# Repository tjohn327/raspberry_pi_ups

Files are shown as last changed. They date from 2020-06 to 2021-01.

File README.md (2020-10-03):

# UPS for Raspberry Pi

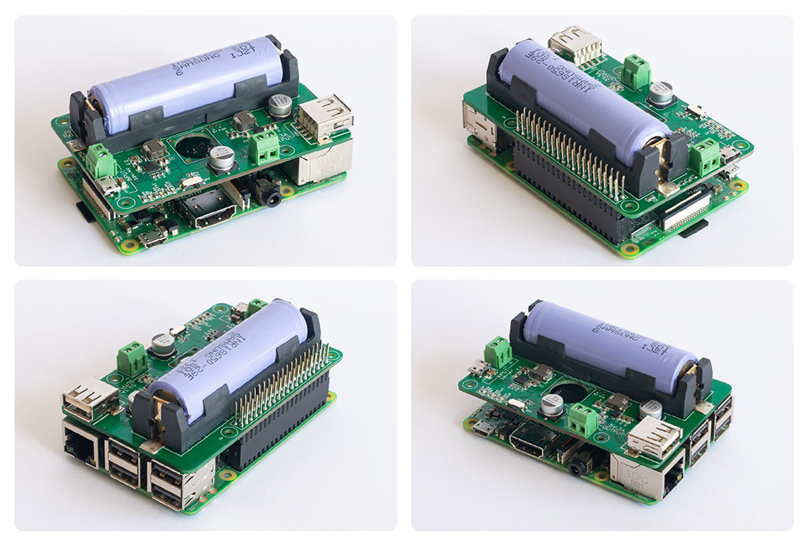
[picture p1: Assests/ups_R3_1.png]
UPS Image UPS powering a Raspberry Pi 3B+ model


## Description

An uninterruptible power supply for Raspberry Pi that can provide more than an hour of backup power and can shutdown the Pi safely.
This UPS can be used to power any 5V device with up to 3A continuous current. It is based on Texas Instruments [BQ25895](http://www.ti.com/product/BQ25895) power management IC and [TPS61236P](http://www.ti.com/product/TPS61236P) boost converter IC.

This UPS can power a Raspberry Pi through the GPIO header by using it as a hat. When used as a hat, the GPIO pins 2, 3 and 4 will be utilized for I2C and interrupt signals.

Note:  

* Do not connect two input sources together!

* The device does not have reverse polarity protection, be sure to observe the polarity marked in the battery holder while inserting the battery.

* UPS script was tested on a Raspberry Pi 3B+ running Raspbian Buster.

## Specifications

* Input:  4.5V - 14V DC, 2A - 5A

* Input Ports: Screw Terminal, micro USB

* Output: 5V, up to 3A

* Output Ports: Screw Terminal, USB A, 40 pin GPIO header for Raspberry Pi

* Battery: Not included (Samsung INR18650-29E recommended, other 18650 size li-Ion batteries can be used)

* Communication: I2C

## Status LEDs

* IN: Input connected or not

* STATUS: ON- Charging, OFF- Charging done, Blinking- Error

* OUT: Output on or off

## Setting up Power Pi for use with a Raspberry Pi

### 1. Connect Power Pi to Raspberry pi

* Make sure the switch of the Power Pi is turned off and no power input is connected to the Power Pi.

* Insert the battery into the battery holder of the Power Pi following the correct polarity.

* Connect Power Pi to Raspberry Pi by inserting it into the GPIO pins.

* Connect a USB power cable into the Raspberry Pi's USB input as usual to turn the Pi on. (This is to set up Power Pi. After the setup, power cable can be connected to Power Pi's input.)

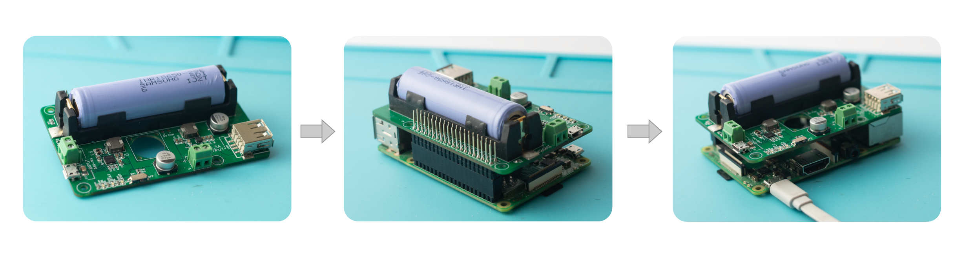
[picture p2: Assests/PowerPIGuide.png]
Setup Steps for setting up Power Pi


### 2. Set up Raspberry Pi to communicate with Power Pi

#### Enable I2C and install smbus

Update the system (optional):

```shell
sudo apt update && sudo apt upgrade -y
```

Enable I2C:

```shell
sudo raspi-config
```

Choose Interfacing Options, then I2C and then select enable to enable I2C in the Raspberry Pi.

Install smbus by running the following command:

```shell
sudo apt-get install -y python-smbus
```

For more information, checkout the [link](https://learn.adafruit.com/adafruits-raspberry-pi-lesson-4-gpio-setup/configuring-i2c)

### 3. Install the ups service

Clone the Power Pi repository:

```shell
cd ~
git clone https://github.com/tjohn327/raspberry_pi_ups.git
cd raspberry_pi_ups/src/
```

Edit the file powerpi.py between lines 16 and 24 if you are not using Samsung INR18650-29E battery. It is recommended to keep the VBAT_LOW at 3.2V for Li-Ion batteries.

*Power PI uses GPIO4 for interrupts from the Power Management IC. 1-Wire interface uses the same pin. If you are not using 1-Wire interface, disable it before proceeding. Power Pi can still function fully without the interrupt. So if you want to use 1-Wire interface it is advised to remove the resistor R12 from Power Pi, otherwise it will cause interference with 1-Wire interface.*

Run the install.sh script to install a service for the ups.

```shell
chmod +x install.sh
./install.sh
```

This creates a service named ups.service that will run on startup.
If there are no errors, you will see this as the output:

```shell
Checking Python
Python found
Initializing Power Pi
INFO:root:UPS initialized
Creating ups service
Enabling ups service to run on startup
ups service enabled
Power Pi configured successfully
```

Don't panic - since the Power is not connected to Power Pi this message will appear.

```shell
Broadcast message from user@raspberry (somewhere) (Sat Aug 15 18:40:10 2020):

Power Disconnected, system will shutdown in 72 minutes!
```

Now turn off the Raspberry Pi and remove the power cable form it. Connect the power cable to Power Pi and turn the switch to ON position. This will power up the Raspberry Pi through Power Pi.

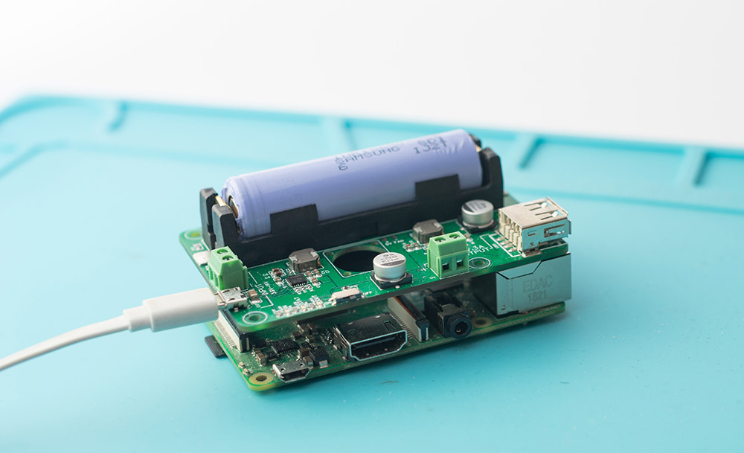
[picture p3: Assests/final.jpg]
PowerPi Power Pi powering the Raspberry Pi


When the Pi is powered back up, check the status of the ups service by running:

```shell
sudo systemctl status ups.service
```

If everything is running correctly, you will see a status similar to this:

```shell
● ups.service - UPS Service
   Loaded: loaded (/lib/systemd/system/ups.service; enabled; vendor preset: enabled)
   Active: active (running) since Tue 2020-06-09 06:44:15 UTC; 34s ago
 Main PID: 542 (python)
    Tasks: 2 (limit: 2200)
   Memory: 6.9M
   CGroup: /system.slice/ups.service
           └─542 /usr/bin/python /home/pi/code/raspberry_pi_ups/src/ups.py

Jun 09 06:44:15 raspberrypi systemd[1]: Started UPS Service.
Jun 09 06:44:17 raspberrypi python[542]: INFO:root:UPS initialized
```

Your Power Pi is now ready.

The ups service will now run on startup and send the status of the UPS to UDP Port 40001 every 2 seconds. You can see the status of the UPS by listening to that port.

To test if the UPS status is being read correctly, run the following command:

```shell
nc -lvu  40001
```

### 4. Setup Node-Red dashboard for visualization (optional)

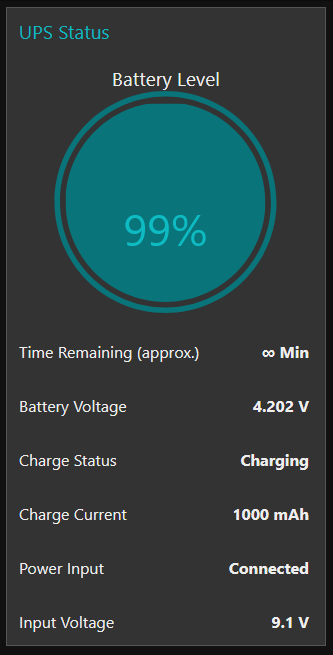
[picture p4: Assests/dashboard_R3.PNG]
Dashboard UPS Monitoring Dashboard


If you are new to Node-Red, please checkout their Essentials [video](https://www.youtube.com/watch?v=ksGeUD26Mw0&list=PLyNBB9VCLmo1hyO-4fIZ08gqFcXBkHy-6) series.

Follow the instructions given in the [link](https://nodered.org/docs/getting-started/raspberrypi) and install Node-Red on the Raspberry Pi.

It may take a while to install. After the installation is done, copy the ups_flow.json file to Node-Red's directory.

```shell
cp ups_flow.json ~/.node-red/lib/flows/ups_flow.json
```

Install the Dashboard extension for Node-Red.

```shell
cd ~/.node-red/
npm i node-red-dashboard
```

Enable Node-Red to run on startup and start the Node-Red service:

```shell
sudo systemctl enable nodered.service
sudo systemctl start nodered.service
```

Open the Node-Red link in a browser. The link is usually:

http://[IP of Raspberry Pi]:1880/

Import the ups flow into the Node-Red environment.

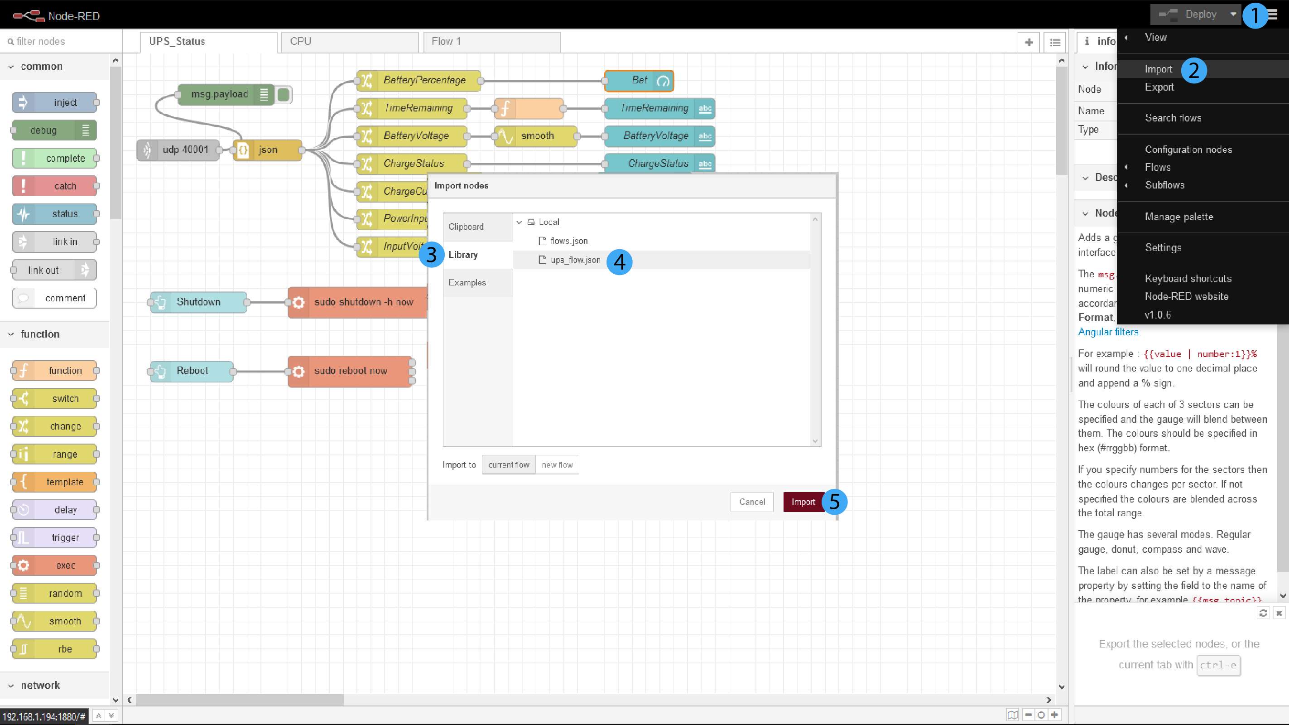
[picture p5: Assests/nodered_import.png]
Import Importing ups flow


Edit one of the UI nodes (e.g BAT) by double clicking on it. In its setup menu click on the edit button next to "Group' and select 'Home' in the Tab drop down. Click Update and then Done.

Deploy the flow by clicking the Deploy button and open the dashboard link of Node-Red to see the status of the UPS.

http://[IP of Raspberry Pi]:1880/ui

More [info](https://nodered.org/docs/user-guide/editor/workspace/import-export) about importing flows and setting up [dashboards](https://flows.nodered.org/node/node-red-dashboard).

## Using Power Pi with Raspberry Pi

When powering the Raspberry Pi through Power Pi, always connect the power cable to the input of the Power Pi. Use the switch of Power Pi to turn the devices ON and OFF.

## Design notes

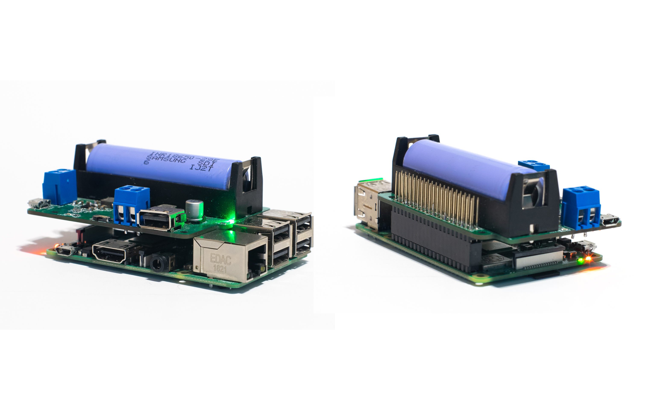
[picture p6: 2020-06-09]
Assests/UPSPi.png

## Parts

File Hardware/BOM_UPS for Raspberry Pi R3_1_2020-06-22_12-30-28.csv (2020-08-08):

ID | Name | Designator | Footprint | Quantity | Manufacturer Part | Manufacturer | Supplier | Supplier Part | LCSC Assembly | Remarks
1 | 10uF | C5,C6,C1,C7,C4,C8 | C0603 | 6 | GRM188R61E106KA73D | Murata Electronics | LCSC | C344022
2 | 10nF | C10 | C0603 | 1 | CL10B103KC8NNNC | SAMSUNG | LCSC | C84709 | Yes
3 | K3-1296S-E1 | SW1 | K3-1296S-E1 | 1 | K3-1296S-E1 | HRO | LCSC | C128955
4 | YJ-USB-AF-SMT-01 | USB1 | USB-A-SMD_FUS270-FSBW5K | 1 | YJ-USB-AF-SMT-01 | ValuePro | LCSC | C8328
5 | 10K | R3,R1,R2,R4,R5,R6,R10 | R0402 | 7 | RC0402FR-0710KL | YAGEO | LCSC | C60490
6 | 47nF | C2 | 402 | 1 | GRM155R71C473KA01D | MuRata | LCSC | C77012
7 | BQ25895RTWR | U1 | QFN-24_4X4X05P | 1 | BQ25895RTWR | TI | LCSC | C80200
8 | 2.2K | R7,R8,R9 | 603 | 3 | RC0603FR-072K2L | YAGEO | LCSC | C114662
9 | DB125-3.81-2P | U4,U6 | CONN-TH_2P-P3.81_L7.4-W7.6 | 2 | DB125-3.81-2P | DIBO | LCSC | C395878
10 | 1M | R11 | R0402 | 1 | RC0402FR-071ML | YAGEO | LCSC | C138033
11 | 19-217/G7C-AN1P2/3T | LED3,LED1 | LED0603-R-RD | 2 | 19-217/G7C-AN1P2/3T | EVERLIGHT | LCSC | C72042 | Yes
12 | 18650 SMD Bat Holder | BAT1 |  | 1 | Made in China |  |  |  |  | BAT1 cannot be in a reflow oven as it will deform. It should be solder after the SMT process.
13 | 33nF | C9 | C0603 | 1 | CL10B333KB8NNNC | SAMSUNG | LCSC | C21117 | Yes
14 | TPS61236PRWLR | U2 | VQFN-9_2.5X2.5 | 1 | TPS61236PRWLR | TI | LCSC | C130295
15 | 200K | R14 | R0603 | 1 | RC0603FR-07200KL | YAGEO | LCSC | C105574
16 | 1uH | L1,L2 | IND-SMD_L7.1-W6.5-P5.60 | 2 | SPM6530T-1R0M120 | TDK | LCSC | C87572
17 | 19-217/R6C-AL1M2VY/3T | LED2 | LED0603-R-RD | 1 | 19-217/R6C-AL1M2VY/3T | EVERLIGHT | LCSC | C72044 | Yes
18 | 10118194-0001LF | USB3 | MICRO-USB-SMD_10118194-0001LF | 1 | 10118194-0001LF | Amphenol ICC | LCSC | C132563
19 | 22uF | C17 | 1206 | 1 | CL31A226KAHNNNE | SAMSUNG | LCSC | C12891
20 | 620K | R13 | R0603 | 1 | CR0603-FX-6203ELF | BOURNS | LCSC | C203713
21 | 220uF | C13,C14 | CAP-SMD_BD8.0-L8.3-W8.3-FD | 2 | UWX1A221MCL1GB | Nichicon | LCSC | C125986
22 | SH-40P-8.5/5.0/10.5 | H2 |  | 1 | SH-40P-8.5/5.0/10.5 |  |  | https://www.alibaba.com/product-detail/Customize-2-20pin-8-5-5_60778133935.html?fullFirstScreen=true |  | H2 is to be inserted from the bottom layer as in the previous orders. Also please take care when soldering H2 as it should be soldered straight. In one of the previous orders one H2 was not soldered straight.
23 | 0 | R12 | R0603 | 1 | RC0603JR-070RL | YAGEO | LCSC | C95177
24 | 1uF | C3,C15 | C0603 | 2 | CL10A105KA8NNNC | SAMSUNG | LCSC | C5673 | Yes
25 | 22uF | C11,C12,C16 | C0603 | 3 | GRM188R61A226ME15D | MuRata | LCSC | C84419

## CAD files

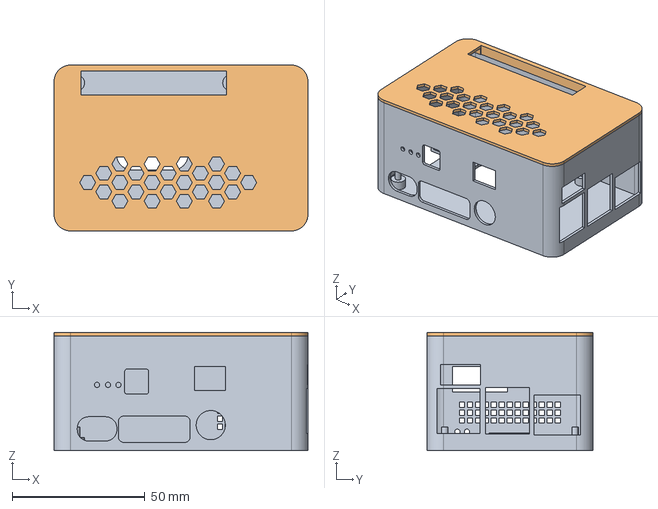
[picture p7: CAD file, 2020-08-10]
Enclosure/Enclosure_RPi4b.step
95.6 x 62.5 x 44.4 mm
Case
Top

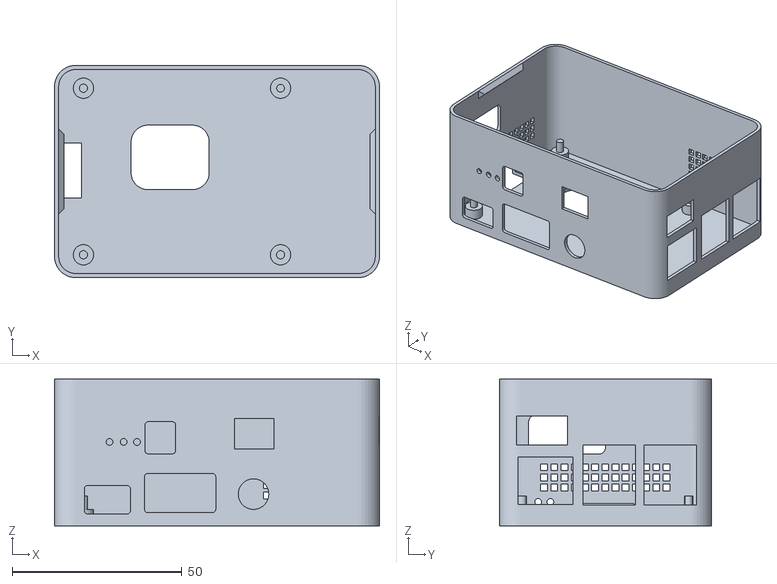
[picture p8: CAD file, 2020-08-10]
Enclosure/STL/RPi3b/Case.stl
95.6 x 62.5 x 43.2

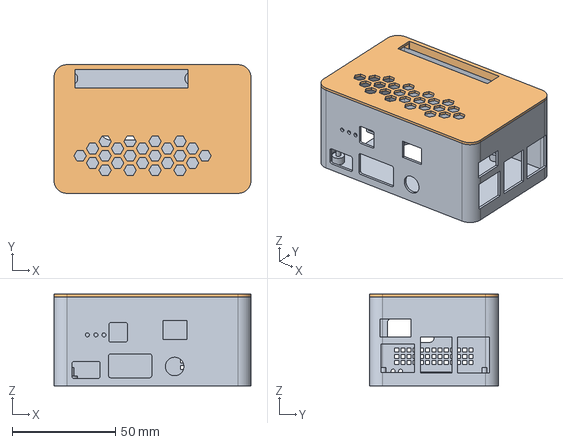
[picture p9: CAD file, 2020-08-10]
Enclosure/Enclosure_RPi3b.step
95.6 x 62.5 x 44.4 mm
Case
Top

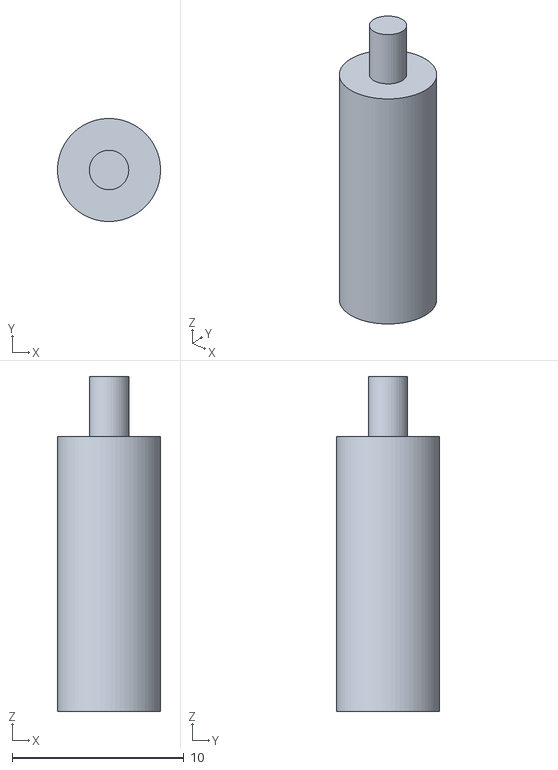
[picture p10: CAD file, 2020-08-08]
Enclosure/STL/RPi3b/Standoff.stl
6.00 x 6.00 x 19.5

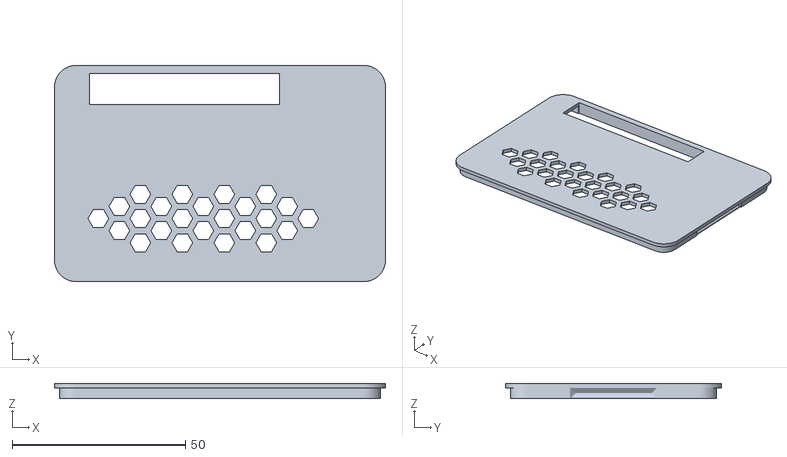
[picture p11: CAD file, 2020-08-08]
Enclosure/STL/RPi4b/Top.stl
95.6 x 62.5 x 4.23

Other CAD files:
Enclosure/STL/RPi4b/Case.stl
Enclosure/Standoff.step
Enclosure/STL/RPi3b/Top.stl

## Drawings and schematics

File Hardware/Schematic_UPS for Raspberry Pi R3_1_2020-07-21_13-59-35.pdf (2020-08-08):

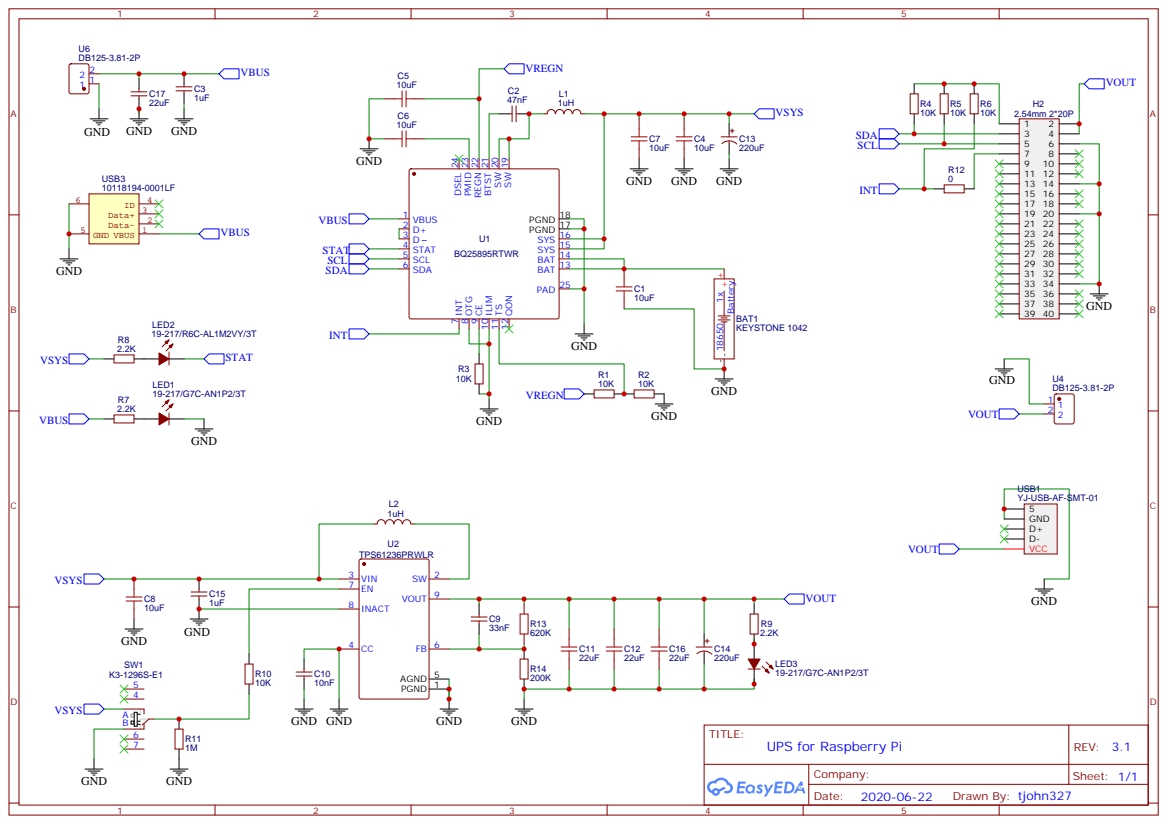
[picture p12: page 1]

BAT 13 BAT 14 SYS 15 SYS 16 PGND 17 PGND 18

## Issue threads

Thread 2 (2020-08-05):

integrate into other monitoring systems

DOliana, 2020-08-05:
I would like to monitor the Power Pi via OpenHab instead of node red. Could you provide some guidance on how monitoring of the Power Pi can be achieved so that it can be integrated into other systems like OpenHab?

tjohn327, 2020-08-05:
The status of Power Pi is being published as UDP message on the port 127.0.0.1:40001 by ups.service.

The messages are JSON formatted as follows:
{
    "BatteryPercentage": 87,
    "BatteryVoltage": 4.08,
    "ChargeCurrent": 0,
    "ChargeStatus": "Not Charging",
    "InputVoltage": 2.6,
    "PowerInputStatus": "Not Connected",
    "TimeRemaining": 76
}

DOliana, 2020-08-08:
thanks for the info - I will look into that. Have you thought about integrating MQTT?

poindexter12, 2020-08-18:
+1 for mqtt

DOliana, 2021-05-02:
If anybody is interested in testing/improving MQTT support - I added MQTT-Support in a [PR](https://github.com/tjohn327/raspberry_pi_ups/pull/10). Please review/improve it.

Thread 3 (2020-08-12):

Device and service failed to run

allibragi, 2020-08-12:
Hi,
I'm trying to setup the powerpi on a Banana PI PRO and, aside that the board is not supported, I'm facing 2 issues:

- Powering the Banana from the PowerPi doesn't work, I've checked the power requirements and the Banana is in the range 5 V @ 2 A

- The installation went ok, the Banana see the PowerPi and give the "Power Pi configured successfully" message, but the service fail to start. Checking the service status I've this error:

> ups.service - UPS Service
   Loaded: loaded (/lib/systemd/system/ups.service; enabled; vendor preset: enabled)
   Active: failed (Result: exit-code) since Wed 2020-08-12 19:43:42 UTC; 16s ago
  Process: 1660 ExecStart=/usr/bin/python /home/banano/raspberry_pi_ups/src/ups.py (code=exited, status=1/FAILURE)
 Main PID: 1660 (code=exited, status=1/FAILURE)
Aug 12 19:43:41 bananapipro systemd[1]: ups.service: Unit entered failed state.
Aug 12 19:43:41 bananapipro systemd[1]: ups.service: Failed with result 'exit-code'.
Aug 12 19:43:42 bananapipro systemd[1]: ups.service: Service hold-off time over, scheduling restart.
Aug 12 19:43:42 bananapipro systemd[1]: Stopped UPS Service.
Aug 12 19:43:42 bananapipro systemd[1]: ups.service: Start request repeated too quickly.
Aug 12 19:43:42 bananapipro systemd[1]: Failed to start UPS Service.
Aug 12 19:43:42 bananapipro systemd[1]: ups.service: Unit entered failed state.
Aug 12 19:43:42 bananapipro systemd[1]: ups.service: Failed with result 'exit-code'.

Anyhow the shipping was perfect and I've received the board without any problems.
Thank you!

tjohn327, 2020-08-12:
Hi,

Banana Pi is not supported by Power Pi for safe shutdown and status monitoring as it was never tested on it. But I guess this issue can be solved.  Nevertheless Power Pi can still power the Banana Pi through the 5V rail of the 40 pin connector if BananaPi supports being powered through the 5V rail. Other wise you'll have to use the USB A output of Power Pi.

For the ups.service file located at /lib/systemd/system/ups.service. See if the path to python and ups.py  after the ExecStart part is correct. Also. check if the username is correct.

tjohn327, 2020-08-12:
Hi,

Banana Pi is not supported by Power Pi for safe shutdown and status monitoring as it was never tested on it. But I guess this issue can be solved. Nevertheless Power Pi can still power the Banana Pi through the 5V rail of the 40 pin connector if BananaPi supports being powered through the 5V rail. Other wise you'll have to use the USB A output of Power Pi.

Check the ups.service file located at /lib/systemd/system/ups.service. See if the path to python and ups.py after the ExecStart part is correct. Also. check if the username is correct.

After correction, run the following:

```shell
sudo systemctl daemon-reload
sudo systemctl enable ups.service
sudo systemctl restart ups.service
```

allibragi, 2020-08-13:
Hi,

I've found the error in the process, it wasn't t able to find the RPi.GPIO library. I've installed it from the manufacturer repo (http://wiki.lemaker.org/BananaPro/Pi:GPIO_library).

For the powering I'm using a cable through the USB port. I think it could be possible to power it through the pins but i can't find any hint (plus I'm not experienced in this field). If anyone should come through this post and knows how to do it let me know.

tjohn327, 2020-08-14:
Hi,
Thank you very much for the feedback.
Have you connected the Power Pi to BananaPi as a HAT using the 40 Pin connector? If so, I don't think you need the cable to Power it, just turn the switch on and it should start powering the Banana Pi.

allibragi, 2020-08-14:
If i connect the Power Pi by the pins and flip the switch the Banana Pi simply don't turn on. The leds on the PowerPi shows that the battery is charging and that the output power is on.
If I power the PI normally the process see the HAT and shows the battery time left and that its not charging (obviously).

tjohn327, 2020-08-14:
That means Banana Pi does not support powering it through the 5V pins of the 40 pin connector.

allibragi, 2020-08-14:
I'll use it by the USB port, is not much a problem. I eventually switch to a PI 4.
Thanks for the help.

Closed 2020-08-14.

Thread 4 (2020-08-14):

Not charging

heronlen, 2020-08-14:
Hi I received the PowerPi, all configured, as per instructions and it runs the Pi when the power is disconnected, however it isn't charging the battery.

Running nc -lvu  40001

Listening on [0.0.0.0] (family 2, port 40001)
Connection from localhost 46547 received!
{
    "BatteryPercentage": 30,
    "BatteryVoltage": 3.504,
    "ChargeCurrent": 0,
    "ChargeStatus": "Not Charging",
    "InputVoltage": 2.6,
    "PowerInputStatus": "Not Connected",
    "TimeRemaining": 26
}

Thanks in advance.

kiddigital, 2020-08-14:
@heronlen , it also says that the PowerInputStatus is 'Not Connected'. So there is no power to charge from :)

Check the powersupply to the PowerPI to make sure the PowerPI gets power at all.

heronlen, 2020-08-14:
Yes, saw that but how would I resolve a no power connected to the PowerPi when it is seated correctly and working the other way round?

tjohn327, 2020-08-17:
@heronlen Power Pi is designed to be powered from the micro usb input port of Power Pi not from the usb input of the Raspberry Pi. Have you connected a power supply to the micro usb input of the Power Pi?  What is the rating of the power supply?

heronlen, 2020-08-17:
@tjohn327 How stupid do I feel?!  Sorry about that.  I missed it in your instructions!  Thanks, all great now.

tjohn327, 2020-08-17:
@heronlen no worries :) Hope you enjoy Power Pi

Closed 2020-08-17.

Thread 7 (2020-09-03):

Error : systemctl status

basswe, 2020-09-03:
sudo systemctl status ups.service
● ups.service - UPS Service
   Loaded: loaded (/lib/systemd/system/ups.service; enabled; vendor preset: enabled)
   Active: active (running) since Thu 2020-09-03 13:43:59 EEST; 43s ago
 Main PID: 800 (python)
    Tasks: 2 (limit: 2200)
   Memory: 3.1M
   CGroup: /system.slice/ups.service
           └─800 /usr/bin/python /home/pi/raspberry_pi_ups/src/ups.py

Σεπ 03 13:44:23 homecontrol python[800]: ERROR:root:a bytes-like object is required, not 'str'

So nothing happened at port 40001.
Bastiaan

basswe, 2020-09-05:
Find the solution.
I was using python3.7 on the raspberry.
Going back to python 2.7 and the error message was gone.
Everything worked (as promised ;-))
Bastiaan.

Closed 2020-09-05.

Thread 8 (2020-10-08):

[question] Will there be another production run?

oblitum, 2020-10-08:
Hi. I sadly missed the first production run of the Power Pi. Will there be another one? I don't have much hardware experience, is it possible/not-that-hard to build it myself with the help of some PCB service that would print less than 5 PCBs?

Schmidt-Heinrich, 2020-11-17:
I would also love to know if there will be another production run.

eitch, 2021-03-04:
I am also looking into ordering a few more, i would like to have them without the 40pin header already soldered. Will this be possible? Or do i need to find another product?

kriznik, 2022-03-29:
I would like to have that info as well. Can't really find any reliable info or contact ... thanks

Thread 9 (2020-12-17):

On\Off oscillation on low battery

VyCOSystems, 2020-12-17:
hi
first of all - great job!

I was replicating the schematic and it working properly,
other than when the battery is low - then the system starts to oscillate.

I didn't change anything in the settings other than the battery capacity (2600ma).

I'm not using GPIO4 - maybe it's related?

thank you,
Coby.

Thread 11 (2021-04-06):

[question] Why VSYS with boost converter and not PMID

ApiumJacob, 2021-04-06:
What was VSYS with a boost converter chosen over using the PMID output of the BQ25895?  I haven't played with the chip yet and I'm trying to figure out why this might be the case.  The only reason I can come up with is that block diagram for the chip makes it look like PMID is only powered when there is power on VBUS.  Where as VSYS can get power from VBUS or VBAT.  However, there is contradicting verbiage (to the block diagram) in the datasheet that indicates that PMID can be power from VBAT.

"8.2.5 Boost Mode Operation from Battery
The device supports boost converter operation to deliver power from the battery to other portable devices
through PMID pin."

I realize that this is probably a better question for Ti but I learned of this chip through this design so I thought the designers of the board might have some insight.  It appears that this design was lifted from the PMP4451 eval board which doesn't use the PMID pin of the BQ25895 as well.

Thanks in advance,

Jacob

NerdyProjects, 2021-05-16:
VSYS is meant to be used to power the system, but is not able to provide 5V. PMID is connected to VIN, when present, so it will only be a regulated voltage when VIN is not present.

SumantKhalate, 2023-03-25:
Hello @ApiumJacob

I'm working on a similar project using BQ25895 and I'll try to answer your question, not sure if that's the actual reason but anyways.

If you look further down in "8.2.5 Boost Mode Operation from Battery" it says

> 5. After 30 ms delay from boost mode enable

This 30ms will cause the power rail to dip, cause a glitch, or restart the pi. Hope this helps

DjordjeMandic, 2024-09-07:
@SumantKhalate is there then any similar ic with all same features but without PMID/OTG mode

SumantKhalate, 2025-07-09:
> [@SumantKhalate](https://github.com/SumantKhalate) is there then any similar ic with all the same features but without PMID/OTG mode

Not that I know of, but you can still use the same IC, leaving the PMID pin unconnected and not using the OTG functionality. You will need an external boost converter if you plan to have a regulated uninterruptible 5V out

DjordjeMandic, 2025-07-09:
> Hello, how about the bq24780S?

BQ24800 would be better choice for new design

rtek1000, 2025-07-09:
The BQ24800 is quite interesting, but it seems to only be applicable to the 12V line. Is there a 5V version?

> 6.4.3.1 Setting Minimum System Voltage in Battery Only Boost Mode
> ...The BQ24800 device provides minimum system voltage range from 5.632-13.568 V (0x1600 - 0x3500), with 256-mV step resolution. Upon POR (power-on-reset), minimum system voltage limit is 8.96 V (0x2300). The regulation voltage during battery only boost mode is either 1.5V or 2.3V above VSYSMIN as set in REG0x38[5].

8.96 + 1.50 = 10.46; 8.96 + 2.3 = 11.26
13.568 + 1.50 = 15.068; 13.568 + 2.30 = 15.868

Practically the usable range seems to be from 10.46V to 15.868V.

https://www.ti.com/lit/ds/symlink/bq24800.pdf

DjordjeMandic, 2025-07-09:
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

Not that i know of, it's mostly used in laptops and devices with 2-4S configurations. Not suitable for rpi unless project needs to supply 12V rail which is useful for sata devices.

I mentioned bq24800 because it's battery power backbone of most modern laptops.

It would suit this project if battery would be 3S (10V-12.6V) with vsys minimum being 11.5V. I guess it's fine for 12V rail to swing from 11.5V to 12.6V

Other voltages can then be derived from VSYS.

But that then results into another problem, when Vin for charging is connected, vsys becomes vin.

Inefficient but simple solution that will not cause power loss(laptop example):
Vin(19V for example) goes into bq24800, charges 4S battery, supplys vsys which is in range from 13V to 19V. Powerpath control exists.

Vsys then goes into 3 buck converters (for 12V, 5V and 3.3V). I guess that there is single chip that can do 3 rails with ability to turn off unused rails (for example 3.3V).

I'm not aware of 5V compatible version that can do "otg" mode fast enough. Maybe we should look into integrated circuits used in mobile phones?

SumantKhalate, 2025-07-09:
I'm thinking of using BQ25798 for 2S LiPo, followed by TPS55288(buck-boost with passthrough).
And BQ28Z610-R1 for the fuel gauge and protection.

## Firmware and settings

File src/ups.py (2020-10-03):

#!/usr/bin/python

import time
import os, sys
import logging
import socket
import json
import signal
from powerpi import Powerpi

logging.basicConfig(level=logging.INFO)
GPIO4_AVAILABLE = True

try:
    import RPi.GPIO as GPIO   
except :
    GPIO4_AVAILABLE = False
    logging.error("Error importing GPIO library, UPS will work without interrupt")

ENABLE_UDP = True
UDP_PORT = 40001
serverAddressPort   = ("127.0.0.1", UDP_PORT)
UDPClientSocket = socket.socket(family=socket.AF_INET, type=socket.SOCK_DGRAM)
disconnectflag = False
ppi = Powerpi()

def read_status(clear_fault=False):
        global disconnectflag, ENABLE_UDP
        err, status = ppi.read_status(clear_fault)
        
        if err:
            time.sleep(1)
            return

        if status["PowerInputStatus"] == "Not Connected" and disconnectflag == False :
            disconnectflag = True
            message = "echo Power Disconnected, system will shutdown in %d minutes! | wall -n " % (status['TimeRemaining'])
            os.system(message)
        
        if status["PowerInputStatus"] == "Connected" and disconnectflag == True :
            disconnectflag = False
            message = "echo Power Restored, battery at %d percent | wall -n " % (status['BatteryPercentage'])
            os.system(message)
        
        if ENABLE_UDP:
            try:
                UDPClientSocket.sendto(json.dumps(status,indent=4,sort_keys=True), serverAddressPort)
            except Exception as ex:
                logging.error(ex)
        
        logging.debug(status)
        
        if(status['BatteryVoltage'] < ppi.VBAT_LOW):
                ppi.bat_disconnect()
                os.system('sudo shutdown now')

def interrupt_handler(channel):
    read_status(True) 

def main():
    if ppi.initialize():
        sys.exit(1)

    if GPIO4_AVAILABLE:
        try:
            GPIO.setmode(GPIO.BCM)
            GPIO.setup(4, GPIO.IN, pull_up_down=GPIO.PUD_UP)
            GPIO.add_event_detect(4, GPIO.FALLING, callback=interrupt_handler, bouncetime=200)
        except Exception as ex:
            logging.error("Error attaching interrupt to GPIO4, UPS will work without interrupt.")
        
    while (True):
        read_status()

if __name__=="__main__":
    main()
                

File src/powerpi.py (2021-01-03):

import smbus
import logging
import time

class Powerpi:
    
    #Refer to http://www.ti.com/lit/ds/symlink/bq25895.pdf for register maps


    ####Edit this section to suit your battery and input specs##############################

    """
    BYTE_ILIM is used to set the input current limit, i.e the maximum current the
    UPS will draw from the power input. It does not affect the output current from
    the UPS. If more current is required at the output than the input is cpabale of,
    the UPS will augment that current from the battery.
    """
    #BYTE_ILIM =  0b01101000 #2A input current limit
    BYTE_ILIM =  0b01111111 #3.25A input current limit
    #BYTE_ICHG =  0b00001000 #.5A charging current limit
    BYTE_ICHG =  0b00010000 #1A charging current limit
    
    VBAT_LOW = 3.2 # Determines the battery voltage at which the UPS will shutoff. 
    
    #Charge Voltage, uncomment the line suitable for your battery type.
    #BYTE_VREG = 0b00000010 #3.84v
    #BYTE_VREG = 0b00010010 #3.9V
    #BYTE_VREG = 0b00101010 #4V
    #BYTE_VREG = 0b01000110 #4.112V
    BYTE_VREG = 0b01011110 #4.208V
    #BYTE_VREG = 0b01110110 #4.304V
    #BYTE_VREG = 0b10001110 #4.4V
    #BYTE_VREG = 0b10101010 #4.512V
    #BYTE_VREG = 0b11000010 #4.608V

    """    
    BAT_CAPACITY, CURRENT_DRAW and VBAT_MAX are used to estimated the state of charge 
    of the battery since there is not current sensor on this UPS. These values along
    with the battery voltage is used to derive the state of charge of the battery.
    
    To make the charge percent of the battery shown more accurate, take a note of
    the battery voltage when charging is complete (red LED turns off after plugging in) 
    and edit the VBAT_MAX to that value.
    
    NB:Changing these values does not affect or change the behavior of the UPS.
    """
    BAT_CAPACITY = 2900 #Battery capacity in mAh
    CURRENT_DRAW = 2000 #Current draw in mAh approximately
    VBAT_MAX = 4.208 #This should be the battery when charged to a 100%

    ##################################################################################


    PORT = 1
    ADDRESS = 0x6a      #I2C address of the ups

    REG_WATCHDOG = 0x07
    BYTE_WATCHDOG_STOP =  0b10001101 #Stop Watchdog timer
    REG_SYSMIN = 0x03
    BYTE_SYSMIN = 0b00010000
    REG_ILIM = 0x00 #ILIM register
    REG_VREG = 0x06 #Charge voltage register

    REG_ICHG = 0x04 
    REG_ICHGR = 0x12
    REG_CONV_ADC = 0x02
    REG_BATFET = 0x09
    BYTE_BATFET = 0b01001000 #delay before battery is disconnected

    REG_CONV_ADC = 0x02
    BYTE_CONV_ADC_START = 0b10011101
    BYTE_CONV_ADC_STOP = 0b00011101
    REG_BATFET_DIS = 0x09
    BYTE_BATFET_DIS = 0b01101000
    REG_STATUS = 0x0B #address of status register
    REG_VBAT = 0x0e
    REG_FAULT = 0x0c
    REG_IBAT = 0x12
    REG_VBUS = 0x11
    

    def __init__(self):
        pass        
        
    def initialize(self):
        try:
            self.bus = smbus.SMBus(self.PORT)
            self.bus.write_byte_data(self.ADDRESS, self.REG_WATCHDOG, self.BYTE_WATCHDOG_STOP)
            self.bus.write_byte_data(self.ADDRESS, self.REG_ILIM,self.BYTE_ILIM)
            self.bus.write_byte_data(self.ADDRESS, self.REG_ICHG, self.BYTE_ICHG)
            self.bus.write_byte_data(self.ADDRESS, self.REG_BATFET, self.BYTE_BATFET)
            self.bus.write_byte_data(self.ADDRESS, self.REG_SYSMIN, self.BYTE_SYSMIN)
            self.bus.write_byte_data(self.ADDRESS, self.REG_VREG, self.BYTE_VREG)
            logging.info("UPS initialized")
            return 0
        except Exception as ex:
            logging.error("Initialization failed, check connection to the UPS:"+ str(ex))
            return 1 
    
    def _int_to_bool_list(self,num):
        return [bool(num & (1<<n)) for n in range(8)]
    
    def _vbat_convert(self,vbat_byte):
        vbat_bool = self._int_to_bool_list(vbat_byte)
        vbat = 2.304
        vbat += vbat_bool[6] * 1.280
        vbat += vbat_bool[5] * 0.640
        vbat += vbat_bool[4] * 0.320
        vbat += vbat_bool[3] * 0.160
        vbat += vbat_bool[2] * 0.08
        vbat += vbat_bool[1] * 0.04
        vbat += vbat_bool[0] * 0.02   
        return vbat
    
    def _ibat_convert(self,ibat_byte):
        ibat_bool = self._int_to_bool_list(ibat_byte)
        ibat = 0
        ibat += ibat_bool[6] * 3200
        ibat += ibat_bool[5] * 1600
        ibat += ibat_bool[4] * 800
        ibat += ibat_bool[3] * 400
        ibat += ibat_bool[2] * 200
        ibat += ibat_bool[1] * 100
        ibat += ibat_bool[0] * 50
        return ibat

    def _vbus_convert(self,vbus_byte):
        vbus_bool = self._int_to_bool_list(vbus_byte)
        vbus = 2.6
        vbus += vbus_bool[6] * 6.4
        vbus += vbus_bool[5] * 3.2
        vbus += vbus_bool[4] * 1.6
        vbus += vbus_bool[3] * 0.8
        vbus += vbus_bool[2] * 0.4
        vbus += vbus_bool[1] * 0.2
        vbus += vbus_bool[0] * 0.1
        return vbus

    def _calc_bat_charge_percent(self,vbat):
        bat_charge_percent = (vbat-self.VBAT_LOW)/(self.VBAT_MAX - self.VBAT_LOW)
        if bat_charge_percent < 0:
            bat_charge_percent = 0
        elif bat_charge_percent > 1:
            bat_charge_percent = 1
        return bat_charge_percent
    
    def _calc_time_left(self,vbat):
        time_left = int(self._calc_bat_charge_percent(vbat) * 60 * self.BAT_CAPACITY / self.CURRENT_DRAW)
        if time_left < 0:
            time_left = 0
        return time_left

    def read_status(self, clear_fault=False):
        try:
            if clear_fault:
                self.bus.read_byte_data(self.ADDRESS, self.REG_FAULT)
            self.bus.write_byte_data(self.ADDRESS, self.REG_CONV_ADC, self.BYTE_CONV_ADC_START)
            time.sleep(2)
            status = self.bus.read_byte_data(self.ADDRESS, self.REG_STATUS)
            status = self._int_to_bool_list(int(status))            
            vbat = self._vbat_convert(self.bus.read_byte_data(self.ADDRESS, self.REG_VBAT))            
            ibat = self._ibat_convert(self.bus.read_byte_data(self.ADDRESS, self.REG_ICHGR))
            vbus = self._vbus_convert(self.bus.read_byte_data(self.ADDRESS, self.REG_VBUS))
            self.bus.write_byte_data(self.ADDRESS, self.REG_CONV_ADC, self.BYTE_CONV_ADC_STOP)
        except Exception as ex:
            logging.error("An exception occurred while reading values from the UPS: " + str(ex))
            time.sleep(2)
            return 1, None
        
        if status[2]:
            power_status = "Connected"
            time_left = -1
        else:
            power_status = "Not Connected"
            time_left = self._calc_time_left(vbat)
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

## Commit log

2019-10-29 Change low voltage threshold to 3.4v
2020-05-27 Powerpi class implemented
2020-05-27 voltages changed to float from string
2020-06-09 Improved user guide
    [BOM_UPS for Raspberry Pi R3_1_2020-06-22_12-30-28.csv, PickAndPlace_PCB_R3_1_2020-06-22_12-30-39.csv]
2020-06-09 Added info about GPIO4 and 1-Wire
2020-06-09 rounded voltage values to 3 dec points.
2020-08-01 Added step files for cases
    [Enclosure_RPi3b.step, Enclosure_RPi4b.step, Standoff.step]
2020-08-01 STL files added
    [Case.stl, Standoff.stl, Top.stl]
2020-08-10 Updated Pi4 Case
    [Case.stl, Enclosure_RPi4b.step]
2020-08-10 Update case files
    [Case.stl, Enclosure_RPi3b.step, Enclosure_RPi4b.step]
2020-08-15 Added charge voltage register
2020-08-24 suppress wall message due to error
    [ups.py]
